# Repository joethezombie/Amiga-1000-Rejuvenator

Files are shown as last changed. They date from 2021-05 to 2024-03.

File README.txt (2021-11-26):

Amiga 1000 Rejuvenator Re-creation Project
-------------------------------------------------------------------------------------------

Any projects, additions, alterations, derivatives, or improvements based on this
Amiga-1000-Rejuvenator project must be openly shared, including software or PLD coding.
Additionally, on top of the LICENSE specified, the amigalove.com logo and Greg Tibbs name
must always be present in digital releases, and prominently printed on physical
productions.

And with that out of the way...

Thanks to the extreme graciousness of Eric Hill (intric8 at amigalove.com), I had on loan
a Rejuvenator board for the Amiga 1000.  Originally created by Greg Tibbs, this Amiga 1000
hardware upgrade provides up to 2MB Chip Memory, an onboard ROM based kickstart, and an
A2000 style video slot.  Installation requires replacing the A1000's daughterboard with
the Rejuvenator.

This project aims to re-create the original Rejuvenator, and eventually improve on the
design.

Schematics and board artwork are complete, and have been fabricated and tested.  Several
design errors on the original Rejuvenator which required bodge wires and trace cuts to
rectify have been identified and eliminated in the new design.

Again, thanks to the unrelenting determination of Eric over at amigalove.com,
arrangements were made to send the board overseas to Matthias Heinrichs of A1K.org who
successfully solved the last piece of the puzzle and has provided the PLD code.
 
 It has been an abosulute pleasure working with these Amiga community staples!
 
 So what now?  The project will continue with the goal of improving on the original
 design.  Currently, work is being done to provide compatibility with Agnus 8375
 varieties (-10, -11, -16, -17) and replace the DRAM with more available surface mount
 options.

--joethezombie

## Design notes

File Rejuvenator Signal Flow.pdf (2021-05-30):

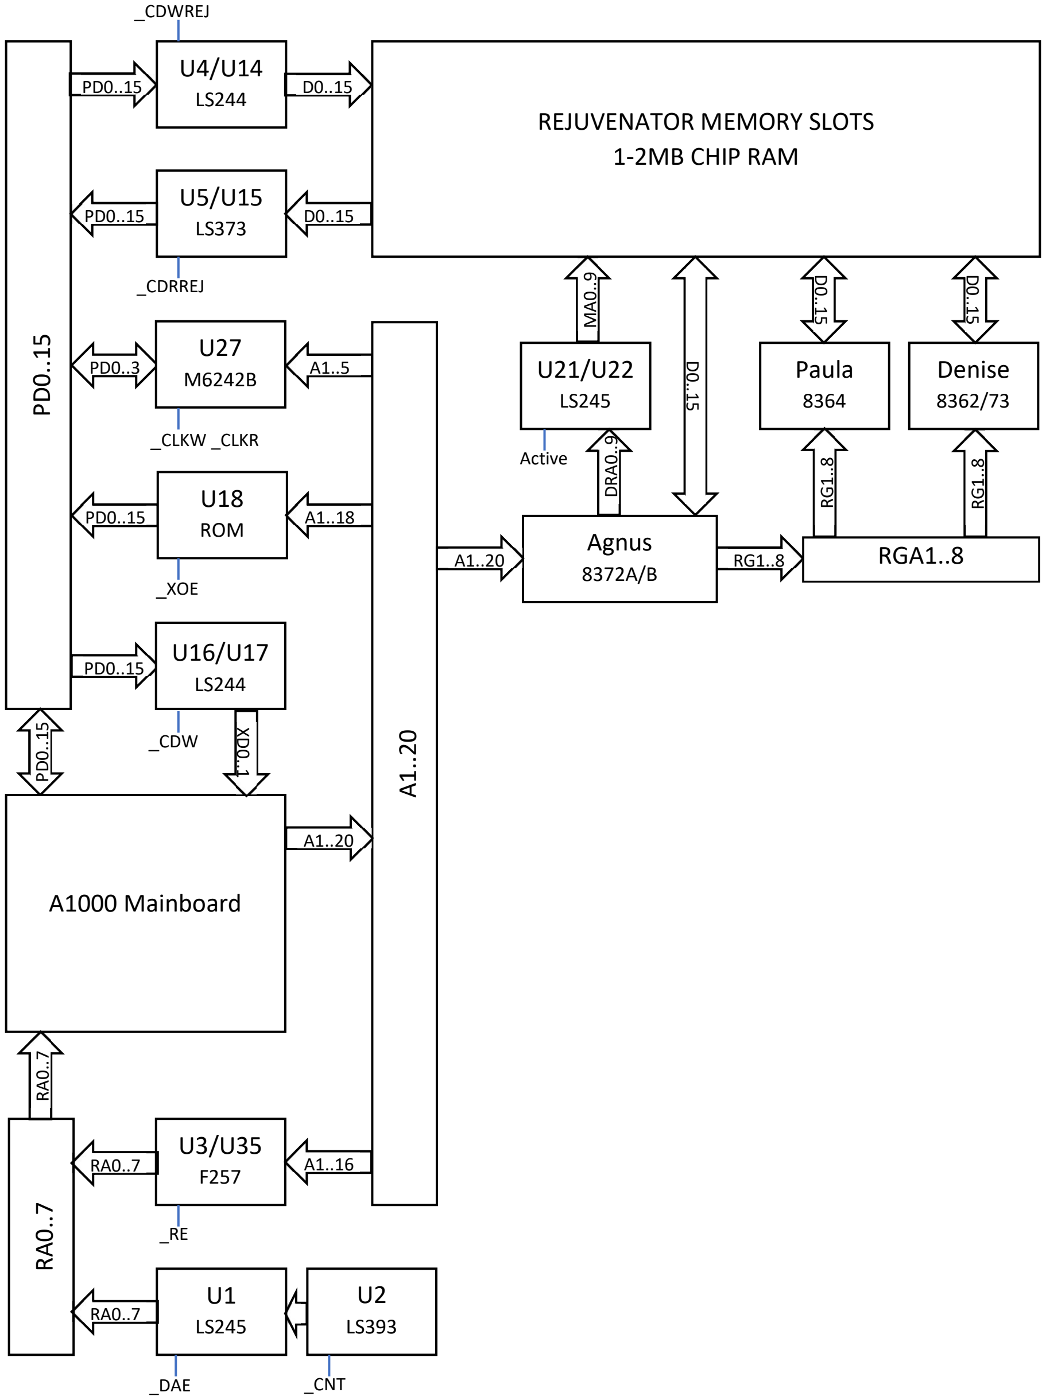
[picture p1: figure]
_CDWREJ; _CDRREJ; Denise; U18 ROM; U16/U17 LS244 PD⁰..15; A1000 Mainboard; _RE RA⁰..7; _DAE; _CNT; REJUVENATOR MEMORY SLOTS 1-2MB CHIP RAM; Paula 8364; Agnus; _XOE; _CLKW _CLKR; _CDW; Active

8372A/B A1..20 | RGA1..8 RG¹..8 | RG¹..8 D0..15 | D0..15 D0..15 DRA⁰..9 MA⁰..9 XD0..1 RA⁰..7

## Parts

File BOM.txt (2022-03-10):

Amiga 1000 Rejuvenator BOM (not yet complete)
----------------------------------------
BOM does not include the Amiga custom chips, ROM, memory, or realtime clock.
BOM values always supersede schematic placeholders

Qty.1  Molex 22-14-2024 CONN RCPT    2POS  X1
Qty.1  Molex 22-14-2044 CONN RCPT    4POS  X14
Qty.1  Molex 22-14-2064 CONN RCPT    6POS  X15
Qty.4  Molex 22-14-2084 CONN RCPT    8POS  U40, U41
Qty.8  Molex 22-14-2104 CONN RCPT   10POS  U36, U37, U38, U39
Qty.1  PLCC CONN SOCKET             84POS  U19 (Agnus)
Qty.2  CONN IC DIP SOCKET   15.24mm 48POS  U20, U25 (Paula, Denise)
Qty.1  CONN IC DIP SOCKET   15.24mm 40POS  U18 (ROM)
Qty.10 CONN IC DIP SOCKET    7.62mm 20POS  U28, U29 (PAL16L8) U6-U16 (RAM Sockets)
Qty.1  CONN IC DIP SOCKET    7.62mm 18POS  U27 (realtime clock)
Qty.2  CONN IC DIP SOCKET    7.62mm 24POS  U30, U31 (PAL20L8)
Qty.6  CONN HEADER VERT MACH 2.54mm 24POS  Circular Machined pin header, 16mm overall length preferred (To mainboard sockets)
Qty.2  47uF  16V Radial Capacitor          C23, C32
Qty.1  220uF 16V Radial Capacitor          C20
Qty.1  22uF  16V Radial Capacitor          C37
Qty.1  20pF  16V CER CAP Radial            C21
Qty.1  ~22pF Trimmer Capacitor             C24 (Fine tune for RTC.  Value should envelope 22pF)
Qty.33 .1uF  16V CER CAP Radial            C30, Decoupling Capacitors
Qty.2  RES ARRAY 8 RES   33 OHM 16DIP      U23, U24
Qty.1  RES ARRAY 9 RES 3.3k OHM 10SIP      RP5
Qty.4  RES ARRAY 9 RES 2.2k OHM 10SIP      RP1, RP2, RP3, RP4
Qty.2  DIODE GEN PURP 100V 200MA DO35      CR1, CR2
Qty.2  SN74AHCT245N                        U26, U34
Qty.3  SN74ALS245AN                        U1, U21, U22
Qty.4  SN74ALS244CN                        U4, U14, U16, U17
Qty.1  SN74LS393N                          U2
Qty.2  SN74ALS373N                         U5, U15
Qty.2  MC74F257AN                          U3, U35
Qty.1  SN74AHCT74N                         U32
Qty.1  T74LS04B1                           U33

Circular Machined pin header WARNING
---------------------------------------------------------------------------------------------------------------------------
Circular Machine pin headers in extended length might be difficult to find.  You can use additional 48-pin sockets to build
the height up on the mainboard before equiping the rejuvenator if necessary. (Thanks to Mattsoft for this observation)

If you use shorter pin headers without extending the socksets, the board will sit very low and will block the power LED
connector.  You should also be mindful of possible shorting on the bottom of the Rejuvenator through hole components against
the CIA and ROM chips on the Amiga 1000 motherboard.  An isolation shim might be a good idea if you opt to sit low.

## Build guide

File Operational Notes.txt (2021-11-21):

Very preliminary... much to do here, stay tuned.

Mainboard:

CAS Header (U5M on mainboard):
    Rejuvenator holds _RGAE and _DAE high, and disconnects _ARW _ROME _PALOPE.
     _ARW leads to pin 16 of original Agnus socket, that pin is unused in Rejuv.
     _ROME connected to Rejuve via EN header, pin 13, then back up CAS header pin 7 where it is unconnected.
     _PALOPE is connected only to expansion port.  Exact function is unknown, perhaps never used.
             No equation present in DPALCAS (pin is nc). Not present in A2000.

EN Header (U5L on mainboard):
     Rejuvenator disconnects _DBR _DAE _RGAE _RE
     _DBR leads to pin 15 of original Agnus socket, that pin is unused in Rejuvenator.
     _DAE and _RGAE held high through mainboard connection to CAS header (see above)
     _RE still connected to Rejvenator via CAS header, pin 8.

  Because _RGAE is held high, LS244 U4J pins 1 and 19 are high.  Disables the Y outputs, leaving output pins in Z state.
  (Disables A1-8 Address lines from hitting the RGA bus)

  Because _DAE is held high, F374 U2H pin 1 is high.  Disables the OE, leaving the output pins in Z state.
  (Disables DRA lines from original Agnus from hitting the RA bus)

Clip Leads to Rejuvenator:
    RMBCLKS clip lead - Reset MainBoard CLocKs - Holds the mainboard clocks in reset using R8/C32 delay timer.  Allows
                        time for the Rejuvenator to initialize before the mainboard becomes active.
    28MHz - Gathers 28MHz from the mainboard.
    12V - 12V from the mainboard, for recharging the clock battery.

  Memory Config Jumpers:
    When using the ROM option (JP100 open), you can configure the mainboard RAM using the J101 and J102:
       J101 J102
        ON   ON   -  C00000 512kb    autoconfig (slow-fast RAM)
        ON   OFF  -  C00000 1Meg     autoconfig (slow-fast RAM) (if you have 1Meg Mainboard Hack?)
        OFF  ON   -  700000 512kb/1M addmem required
        OFF  OFF  -  A80000 512Kb/1M addmem required
             
    When JP100 is closed, Rejuvenator will store 256K ROM file from disk into the front RAM expansion.
    The remaining 256K on the mainboard can be moved to A0000 or 70000 by changing J101 and J102.
       J101 J102
        X    X    -  F00000-FFFFFF WCS 256K/512K Addmem
        OFF  ON   -  700000-7FFFFF Addmem Required
        OFF  OFF  -  A8000-B7FFF   Addmem Required

  Signals:

    _ROM01 - generated on pin 12 of U29, SBGCAS
    If _ROM01 is low: Enable the ROM chips at motherboard positions U2N, U2P, U5N, U5P.
    (ROM01 is connected to Pin 22 (OE) of all 4 ROM positions on the mainboard.

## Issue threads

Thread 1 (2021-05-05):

Verify signal names, states (input, output, or bidirectional), and polarity (active low).

joethezombie, 2021-05-05:
Currently, most of the signals are not directional.  The signal names are also not standardized to Amiga schematics.  Finally, need to identify which signals are active low.

joethezombie, 2021-05-13:
Signal names for the [PAL diagrams](https://github.com/joethezombie/Amiga-1000-Rejuvenator/blob/master/PLD/PAL%20Best%20Guess%20Effort.pdf) have been updated, including active low identification.  Next up will be the schematics.

joethezombie, 2021-05-15:
Signal names on the board schematics and artwork have been mostly updated, including active low identification.  Directional or 3-state adjustments are still needed.

joethezombie, 2021-05-27:
Added signal direction for Agnus 8372B

joethezombie, 2021-05-30:
Signal direction mostly completed.  Schematics now pass ERC check error free!  Will continue to look at the remaining warnings.

graphiteavatar, 2021-05-30:
Very cool. Has there been any forward motion on the PAL chips.  I have some friends that may be able to extract the information, but is that already done and now it’s just deciding it?  I an going to  finish cleaning and testing mine and hopefully there is no damage to my pals.

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

joethezombie, 2021-05-30:
> Very cool. Has there been any forward motion on the PAL chips.

Slowly working forward on the PAL front.  I was unable to read them.  You can read of my strategy and efforts in the PLD folder.

The PALs are fuse-protected, and since they are early PALs and not GALs, they are not susceptible to the voltage manipulation bypass used on GALs.    Further, they use feedback, which forms a rudimentary memory system making analysis very difficult.  Finally, U30 and U31 are larger PALs (20L8) so current tools developed mainly for 16L8 are not easily adapted to the increased number of inputs/outputs.

But I remain hopeful.  Intric8 from amigalove.com (the owner of the board) is working with a1k.org, a much more capable team with a impressive history of reverse engineering, who are very familiar with the native signaling.  Perhaps they will have much better luck on that front.

In the meantime, I am continuing my efforts.  I've recently completed a memory/function map which details whats happening on the board, and what chip enables are toggled depending on memory addresses.  Using that, I hope to create  baseline  logic to at least get the board to boot.  From there we can add memory mapping and expansion port compatibility.

But I'm very interested.  If you and your friends are able to read yours, that would be insanely awesome.  It's the last piece of the puzzle!

graphiteavatar, 2021-08-29:
Hello. Is there a schematic or can you point out the clip lead layout. The rejuvinator mother board was damaged and i can see the reclk silkscreen but can’t se which of the other two is what.  Thanks.

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

joethezombie, 2021-08-31:
The full schematics and board artwork are available in the [KiCAD](https://github.com/joethezombie/Amiga-1000-Rejuvenator/tree/master/KiCAD/Amiga-Rejuvenator) folder.  Use KiCAD to view it.  To directly answer your question, there are 3 clip leads that lead to the Amiga 1000.  RMBCLKS is near the Kickstart selection jumper.  28MHZ is above the battery close to R1.  And +12V is between C29 and the battery.  Consult the [Rejuvenator Manual](http://amiga.resource.cx/manual/Rejuvenator.pdf) for exact placement of the clips on the A1000 mainboard.
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

graphiteavatar, 2021-08-31:
Thanks. I used that pic and soldered them back on. I am thinking the battery damage is too extensive and I am going to have to replace the pc board.  My machine won’t boot.

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

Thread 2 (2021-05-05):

BOM missing

joethezombie, 2021-05-05:
Upload BOM listings.

joethezombie, 2021-05-06:
Partial BOM uploaded.  Stay tuned...

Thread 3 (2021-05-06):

Update board silkscreen with proper capacitor and resistor values

joethezombie, 2021-05-06:
Current silkscreen was best-guess effort.  Proper values were gleaned of intric8's actual Rejuvenator board.  Need to update the artwork with the proper values.

joethezombie, 2021-05-15:
Artwork has been updated to actual build values.

Closed 2021-05-15.

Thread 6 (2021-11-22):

Replace 28MHz clip-lead with PLL

nonarkitten, 2021-11-22:
Clip leads are notoriously risky.

A 4046 could be used to regenerate the 28MHz clock from a 7 or 14MHz source. There seem to be a few options for the clock source, CDAC is probably the best one from Denise. A simple RC with a pF varicap ought to allow for tuning of the clock if there's a problematic phase shift, but I doubt it's needed.

joethezombie, 2022-03-10:
Sorry for the late reply... I wasn't getting notifications of opened issues.

Thanks for this.  I'll look into it for the improved version of the board.

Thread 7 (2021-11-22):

No 12V should be needed for RTC

nonarkitten, 2021-11-22:
Clip leads are dangerous.

I'm assuming the 12V was used for the RTC because 5V wasn't always 5V and would have made the battery more difficult to charge. Or because Commodore being cheap, didn't want a Lithium rechargeable cell and opted for Nickel Cadmium time-bombs.

It would be a big improvement to simply use 5V and a lithium rechargeable coin cell battery as-per the datasheet. These are much more common nowadays and removes the need to pull 12V from anywhere as well as the potentially explosive NiCd.

ogg1e, 2022-01-02:
Was this not updated to support coin cell batteries? Is it attempting to charge them if you install one?

joethezombie, 2022-03-10:
Sorry for the late reply... I wasn't getting notifications of opened issues.

I agree completely with your observations.  This first iteration was meant to exactly copy the original design before any upgrades were made.  A new board is in design that will improve the RTC circuit, including battery type.  Alternative Agnus support will also be included, as well as more available surface mount RAM options.  We just wanted to make sure everything worked as expected before any changes.

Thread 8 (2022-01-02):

bom and schematic don't match

ogg1e, 2022-01-02:
BOM has 47uF for C32, schematic says 22uf.

BOM also doesn't state what caps are polarity and which aren't. Schematic states they all have polarity, but is that true?

joethezombie, 2022-03-10:
Sorry for the late reply... I wasn't getting notifications of opened issues.
The BOM always supersedes schematic placeholders.
As far as capacitor polarity, all electrolytic capacitors on the board are polarized.  Ceramic decoupling capacitors are not.

ogg1e, 2022-05-21:
Sorry, but I mean the schematic file in kicad, not the silkscreen.
The board I have shows R1 = 33 ohm on the silkscreen, but when you open up the sch in kicad, it's 47 ohm.

R1 is not listed in the BOM at all. What do I use for R1 in this situation?

Acill, 2022-05-21:
I have a 33 in mine.

On Sat, May 21, 2022 at 12:42 PM Gary Ogden ***@***.***>
wrote:

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

joethezombie, 2022-05-27:
R1 is interesting because the original bare Rejuvenator board is marked 33Ω.  But original populated boards have been found with 33Ω, 47Ω, or 68Ω resistors.  Consensus was it probably doesn't matter much.  It's there to protect Agnus from the flying lead connection, which isn't optimal.  Work is being done on the next revision of the board to eliminate the flying leads.

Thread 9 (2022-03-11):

Holes for Battery to small

olDirdey, 2022-03-11:
To small hole diameter at the batterie footprint. You can´t install a batterie without altering the legs.

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

joethezombie, 2022-03-11:
Thank you for reporting the issue.  The holes were made the same diameter as the original Rejuvenator, and a test fit with a battery I had on hand did fit.  Most likely new production batteries are not identical to ones from back in the day.  In any event, I will increase the diameter size to accommodate.

Also, please note the recent (yesterday) additions for the capacitors in the RTC circuit now located in the BOM.  The schematic values were placeholders.  The correct values for C21 and C30 have now been added, as well as a reference for the trimmer capacitor C24.

olDirdey, 2022-03-12:
Thank you joe for your reply. That´s true, most of the old style batteries have narrower legs. I measured 5 batteries from 2 different brands that I have laying around. They are between 0.98mm up to 1.04mm.

Good hint pointing out the parts for the RTC. I used parts that are common on memory expansions (22pf near clock and 100uf near batterie) but I will change the bigger 100uf near batterie to 0.1uf.

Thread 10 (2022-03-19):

PCB bit to wide in PSU direction

olDirdey, 2022-03-19:
Build and installed a few Rejuventors. All have in common that the space between PCB and PSU is not enaugh. Had to remove at least one PSU Screw to get the Rejuvenator fitted.

1) Yellow rectangle; Make PCB a bit smaller (1-1.5mm) to get more space between PSU and Rejuvenator Board.
2) Red rectangle; Add a notch to the pcb to get room for the grommet that holds the cable from psu to the mainboard.

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

Acill, 2022-03-19:
While true if you install it while the mainboard  is in the case like I
believe you have been, the manual for the original boards states to remove
the mainboard for the installation. I have found all the ones I do with it
out of the case work great and will go back in all together much easier.

-Paul R.
Acill

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

olDirdey, 2022-03-19:
The manual states it for easier installation. But the position is every time the same, you can´t move the rejuvenator if it´s installed.
So no difference if I install it inside the case or outside the case, the Space between PSU and Rejuvenator is to small. If the Rejuvenator is installed on the board the mounting holes for the psu did not align anymore.

Acill, 2022-03-26:
I  wonder if something changed in the board size from the original release
files to the current? I didnt have any problems with mine. I guess I need
to build another one from the current downloaded repository and see.

-Paul R.

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

olDirdey, 2022-03-26:
Must have to do with the Case, the PSU or somehting like that. Didn´t figured it out yet. I build few Rejuvenators. Some people have no problem with missing space, other as I do, have.

joethezombie, 2022-05-27:
Interesting enough, the reproduction board is actually narrower than the original for just this reason.  The angle You are the only one I know of with this issue.  The angle at the top left of the board was also made deeper to allow better clearance for the peg that fits there, as well as the hole in the middle of the board being larger.

I think we can shave a couple more mm off the edge of the board where the power supply sits without issue.  About how much more room are you needing?

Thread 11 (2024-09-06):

Video Slot

reinauer, 2024-09-06:
The original Rejuvenator had an A2000 video slot on a small riser board. Does this riser exist as a reproduction?

joethezombie, 2024-09-06:
Nearly... I created the schematics and board files.  I hope to test functionality this fall, as real life calms a bit.  Here's the teaser:
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

reinauer, 2024-09-07:
Wow very cool!

neurohide, 2025-03-15:
Wow, I would like to test it with the rgb2hdmi project, the cpld version for amiga 2000, do you think it is possible?

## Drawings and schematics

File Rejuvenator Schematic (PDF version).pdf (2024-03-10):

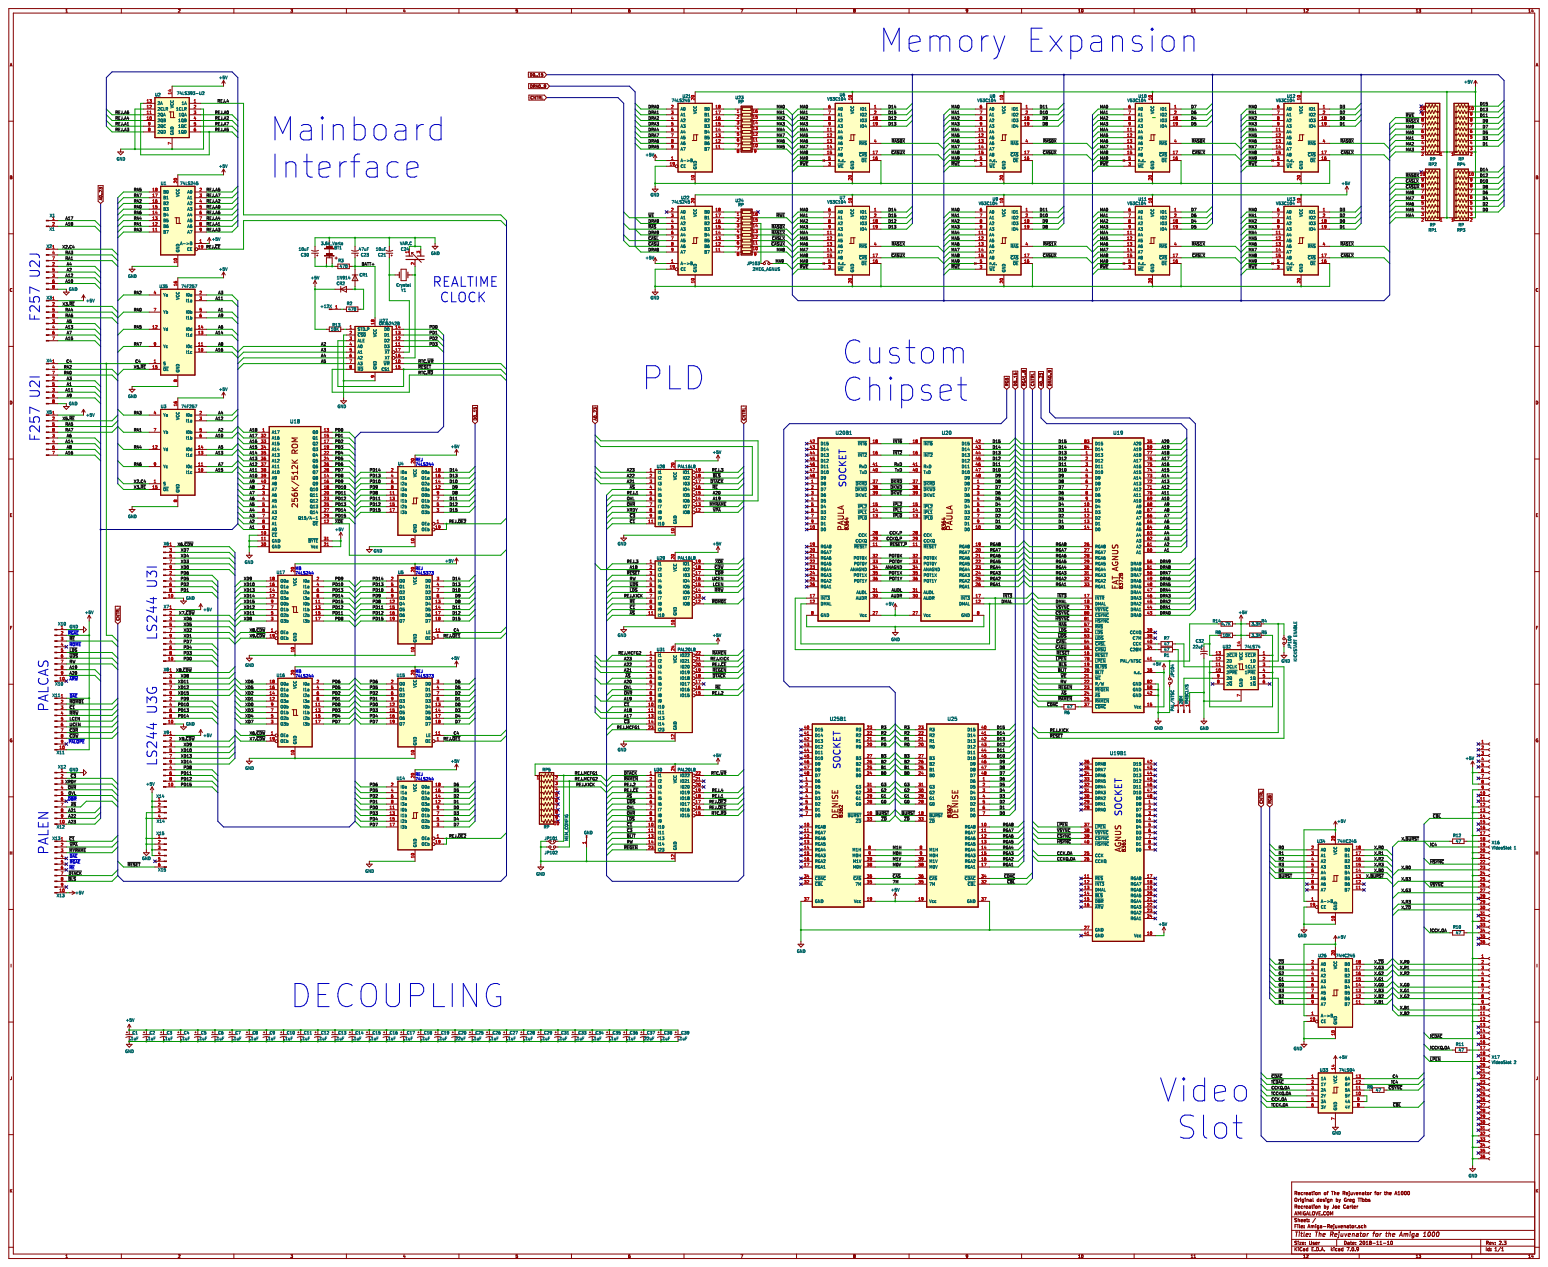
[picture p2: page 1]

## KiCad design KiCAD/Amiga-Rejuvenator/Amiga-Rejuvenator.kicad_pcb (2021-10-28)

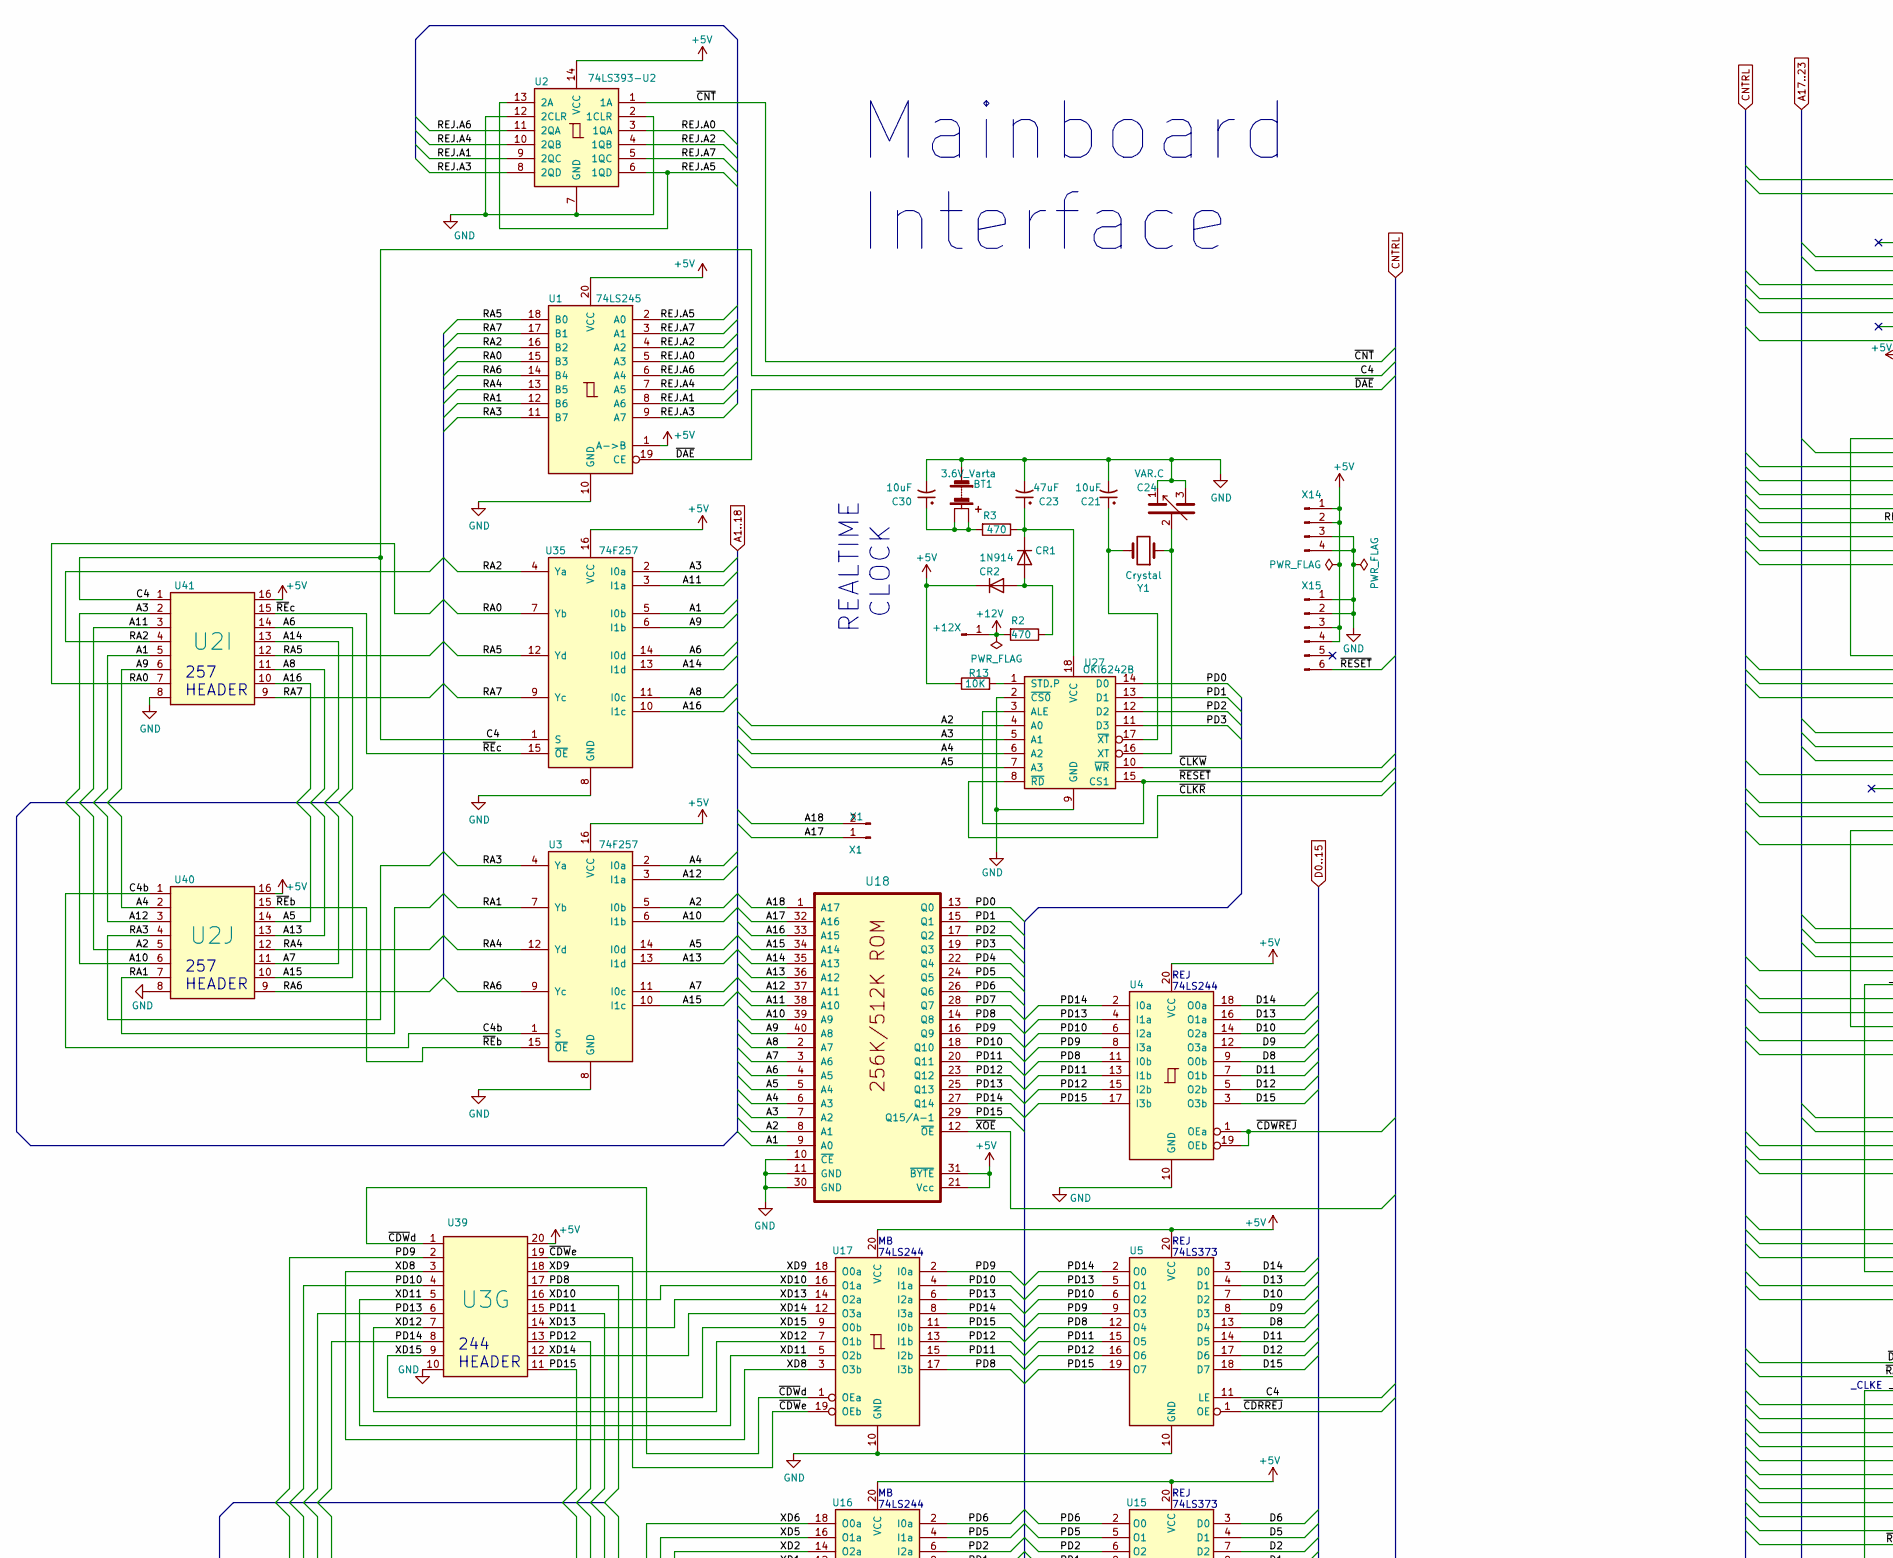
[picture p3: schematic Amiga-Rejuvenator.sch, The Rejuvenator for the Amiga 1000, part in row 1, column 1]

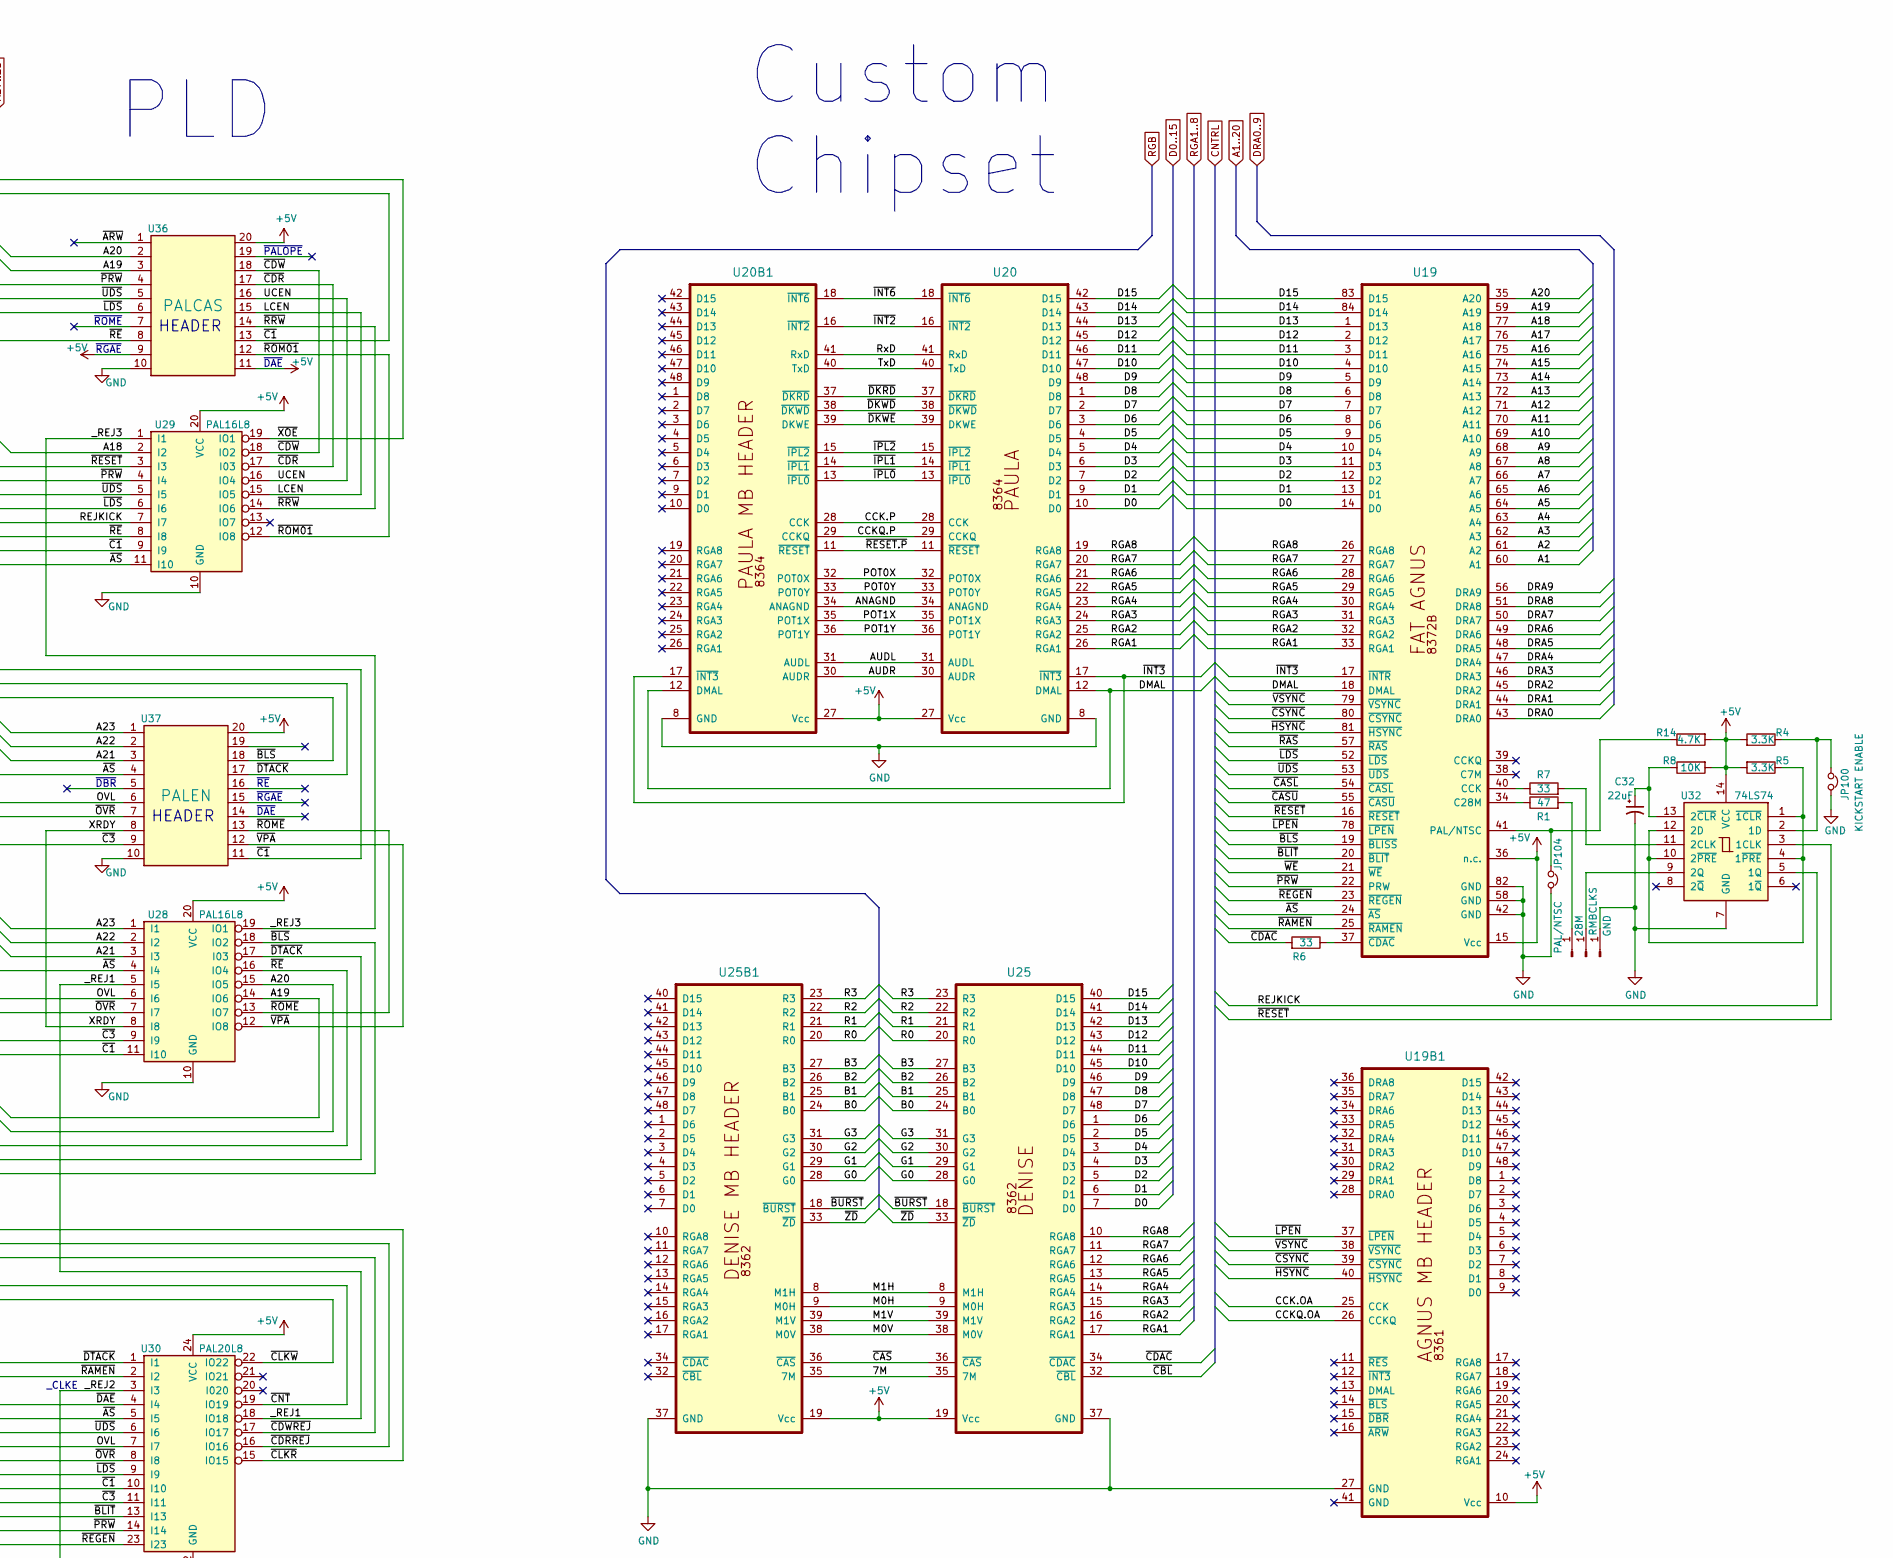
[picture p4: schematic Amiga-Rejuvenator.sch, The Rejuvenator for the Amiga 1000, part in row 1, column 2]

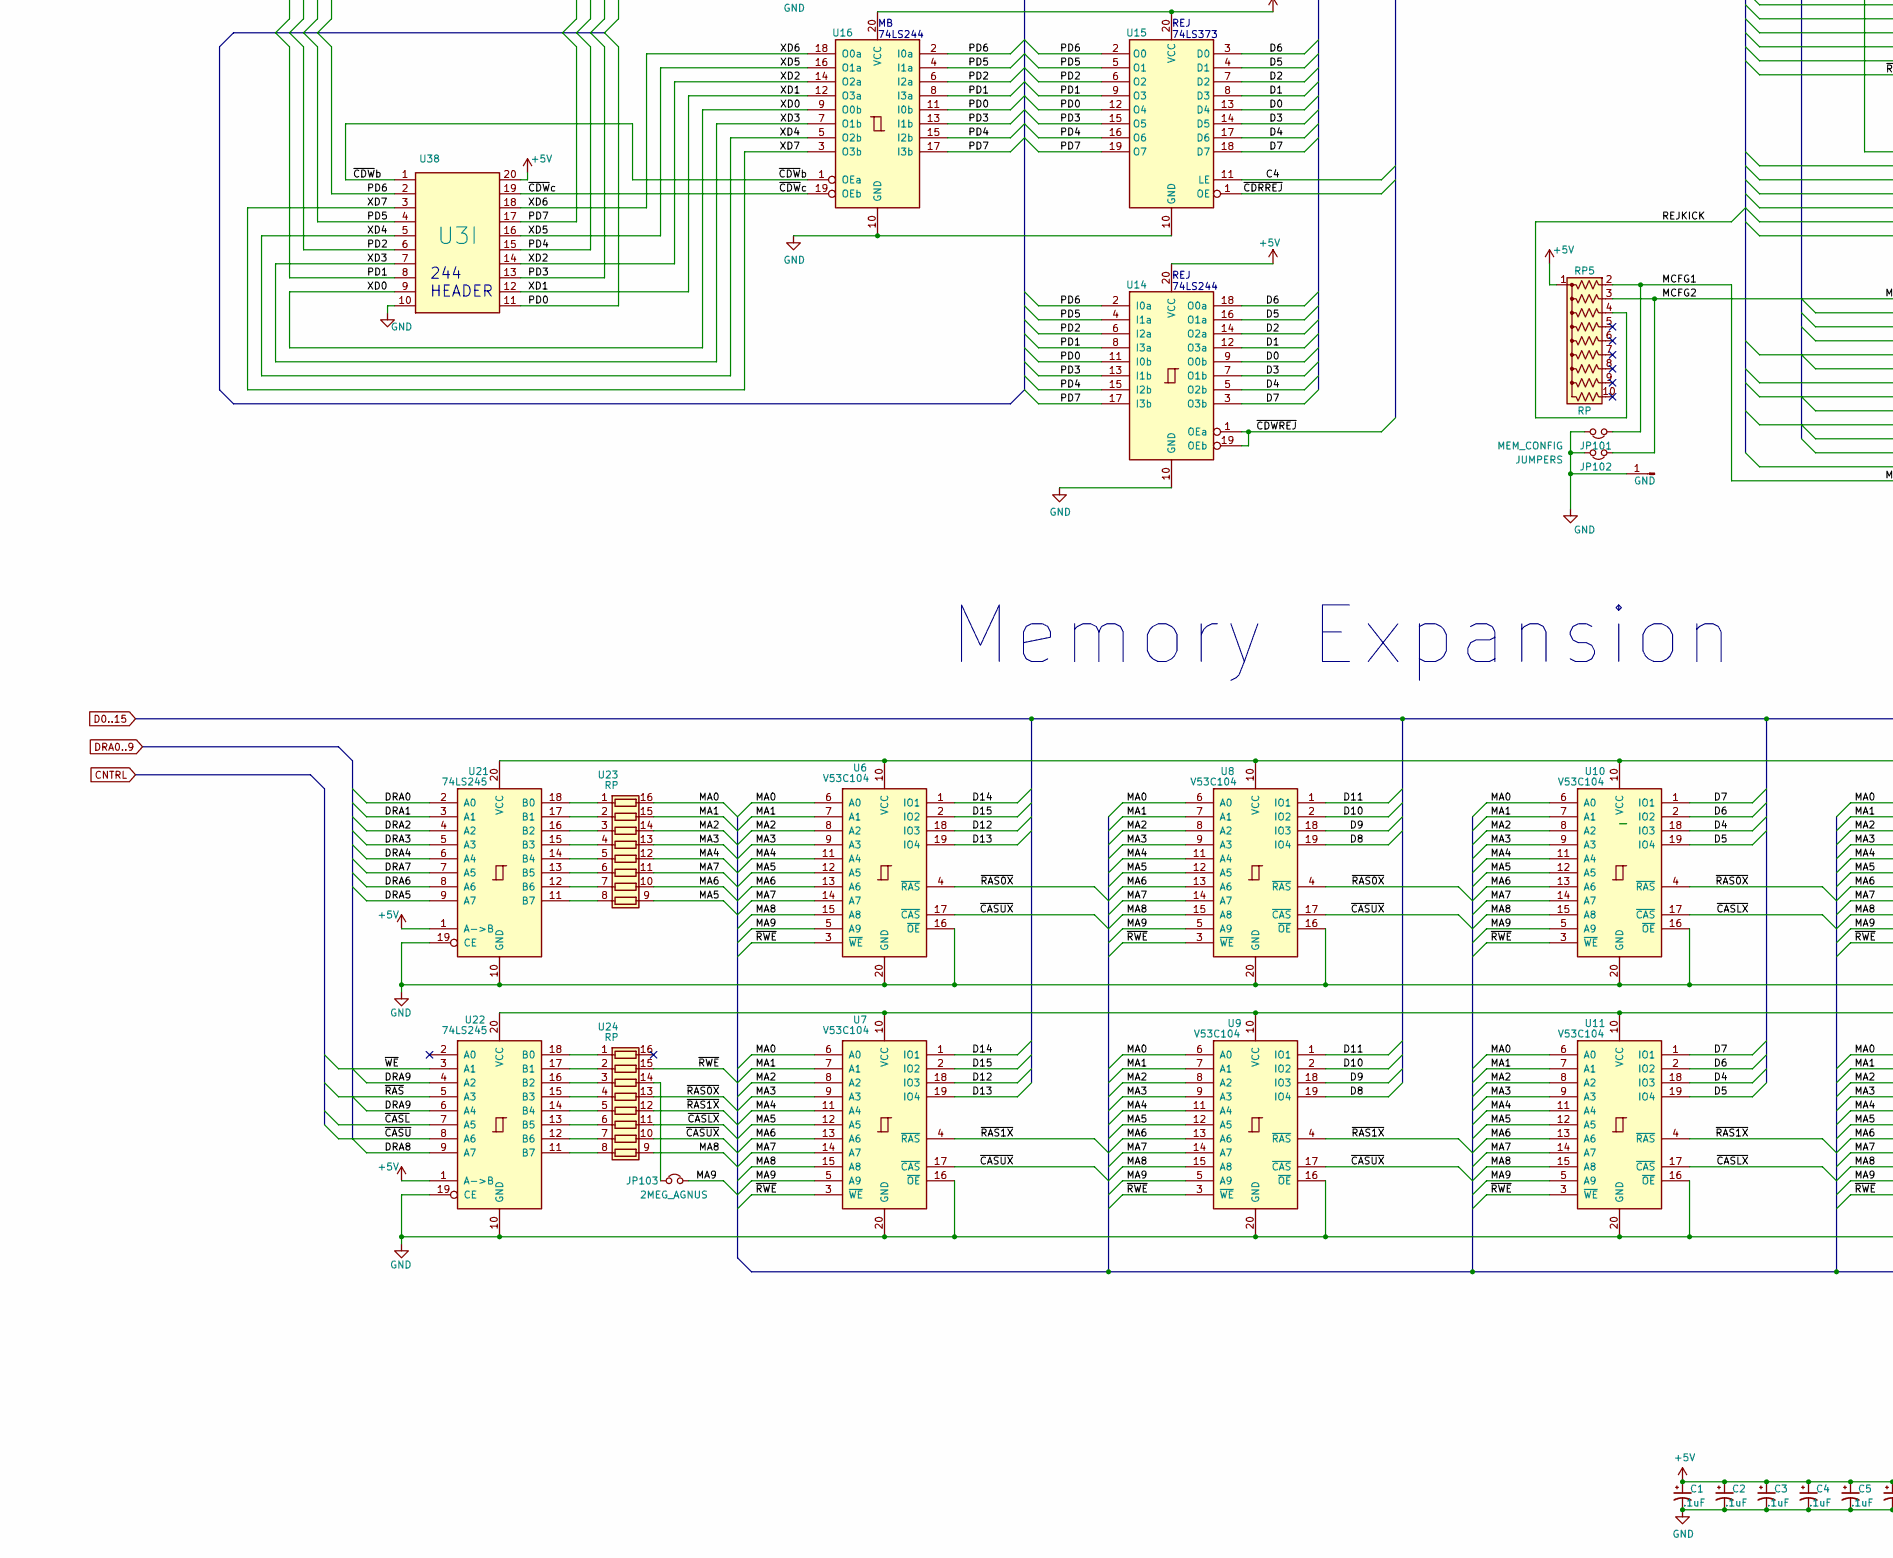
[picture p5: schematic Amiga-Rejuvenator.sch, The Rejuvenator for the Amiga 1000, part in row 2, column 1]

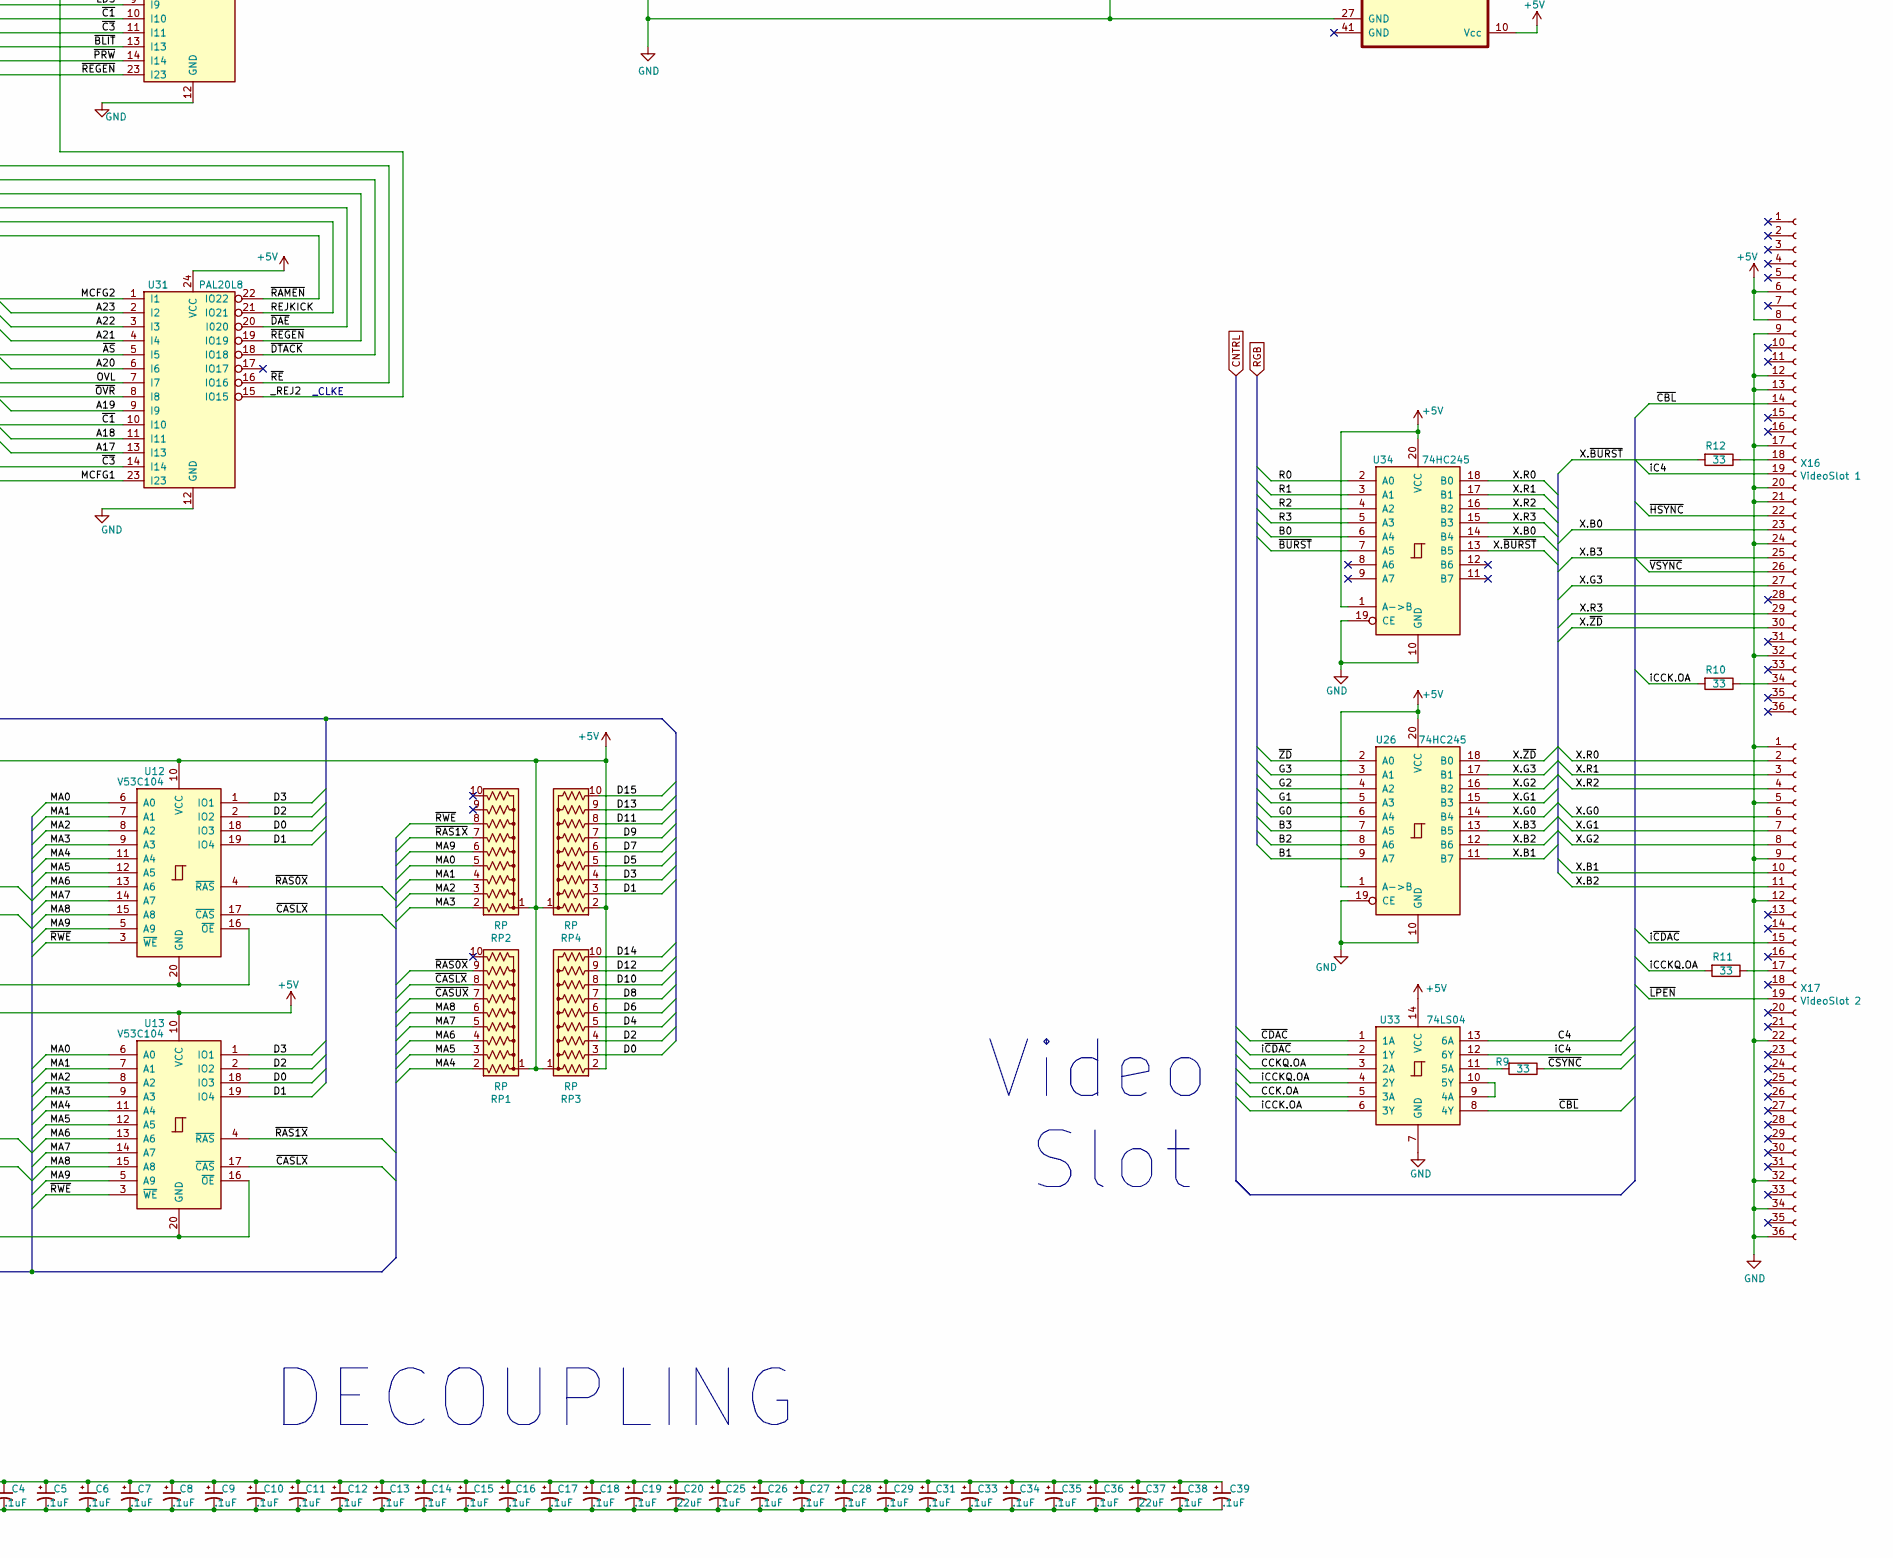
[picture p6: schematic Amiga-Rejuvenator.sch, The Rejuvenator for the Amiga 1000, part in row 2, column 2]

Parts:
BT1: 3.6V_Varta; 3.6V Varta
C1, C2, C3, C4, C5, C6, C7, C8, C9, C10, C11, C12, C13, C14, C15, C16, C17, C18, C19, C25, C26, C27, C28, C29, C31, C33, C34, C35, C36, C38, C39: .1uF; C_Rect_L7.0mm_W2.0mm_P5.00mm
C20, C32, C37: 22uF; C_Rect_L7.0mm_W2.0mm_P5.00mm
C21, C30: 10uF; C_Rect_L7.0mm_W2.0mm_P5.00mm
C23: 47uF; C_Rect_L7.0mm_W2.0mm_P5.00mm
C24: VAR.C; variable_capacitor
CR1, CR2: 1N914; D_DO-35_SOD27_P12.70mm_Horizontal
J1, J18: GND; PinHeader_1x01_P2.54mm_Vertical
J15: 28M; PinHeader_1x01_P2.54mm_Vertical
J17: RMBCLKS; PinHeader_1x01_P2.54mm_Vertical
J19: +12X; PinHeader_1x01_P2.54mm_Vertical
JP100: KICKSTART ENABLE; PinHeader_1x02_P2.54mm_Horizontal
JP101: MEM_CONFIG; PinHeader_1x02_P2.54mm_Vertical
JP102: JUMPERS; PinHeader_1x02_P2.54mm_Vertical
JP103: 2MEG_AGNUS; PinHeader_1x02_P2.54mm_Vertical
JP104: PAL/NTSC; PinHeader_1x02_P2.54mm_Vertical
R1: 47; R_Axial_DIN0207_L6.3mm_D2.5mm_P15.24mm_Horizontal
R2, R3: 470; R_Axial_DIN0207_L6.3mm_D2.5mm_P15.24mm_Horizontal
R4, R5: 3.3K; R_Axial_DIN0207_L6.3mm_D2.5mm_P15.24mm_Horizontal
R6, R7: 33; R_Axial_DIN0309_L9.0mm_D3.2mm_P12.70mm_Horizontal
R8, R13: 10K; R_Axial_DIN0207_L6.3mm_D2.5mm_P15.24mm_Horizontal
R9, R10, R11, R12: 33; R_Axial_DIN0207_L6.3mm_D2.5mm_P15.24mm_Horizontal
R14: 4.7K; R_Axial_DIN0309_L9.0mm_D3.2mm_P12.70mm_Horizontal
RP1, RP2, RP3, RP4, RP5: RP; R_Array_SIP10
U1, U21, U22: 74LS245; DIP-20_W7.62mm
U2: 74LS393-U2; DIP-14_W7.62mm
U3, U35: 74F257; DIP-16_W7.62mm
U4, U14, U16, U17: 74LS244-U16,U17; DIP-20_W7.62mm
U5, U15: 74LS373; DIP-20_W7.62mm
U6, U7, U8, U9, U10, U11, U12, U13: V53C104; DIP-20_W7.62mm
U18: 512K-ROM; DIP-40_W15.24mm
U19: 8372-FatAgnus; PLCC-84_THT-Socket
U19B1: 8361-Agnus-Socket; DIP-48_W15.24mm_Socket
U20: 8364-Paula; DIP-48_W15.24mm_Socket
U20B1: 8364-Paula-Socket; 48pin_blank_socket
U23, U24: RP; DIP-16_W7.62mm
U25: 8362-Denise; DIP-48_W15.24mm_Socket
U25B1: 8362-Denise-Socket; 48pin_blank_socket
U26, U34: 74HC245; DIP-20_W7.62mm
U27: OKI6242B; DIP-18_W7.62mm
U28, U29: PAL16L8; DIP-20_W7.62mm
U30, U31: PAL20L8; DIP-24_W7.62mm
U32: 74LS74; DIP-14_W7.62mm
U33: 74LS04; DIP-14_W7.62mm
U36: PALCAS; MOLEX_4455-10_W7.62mm[x2-R]
U37: PALEN; MOLEX_4455-10_W7.62mm[x2-R]
U38: U3I; MOLEX_4455-10_W7.62mm[x2]
U39: U3G; MOLEX_4455-10_W7.62mm[x2]
U40: U2J; MOLEX_4455-8_W7.62mm[x2]
U41: U2I; MOLEX_4455-8_W7.62mm[x2]
X1: X1; MOLEX_4455-2_W7.62mm
X14: X14; MOLEX_4455-4_W7.62mm
X15: X15; MOLEX_4455-6_W7.62mm
X16: VideoSlot 1; PinHeader_2x18_P2.54mm_Vertical
X17: VideoSlot 2; PinHeader_2x18_P2.54mm_Vertical
Y1: Crystal; Crystal_AT310_D3.0mm_L10.0mm_Vertical

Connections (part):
+5V: C1.1, C2.1, C3.1, C4.1, C5.1, C6.1, C7.1, C8.1, C9.1, C10.1, C11.1, C12.1, C13.1, C14.1, C15.1, C16.1, C17.1, C18.1, C19.1, C20.1, C25.1, C26.1, C27.1, C28.1, C29.1, C31.1, C33.1, C34.1, C35.1, C36.1, C37.1, C38.1, C39.1, CR2.1 (K), R4.2, R5.2, R8.2, R13.1, R14.2, RP1.1 (common), RP2.1 (common), RP3.1 (common), RP3.2 (R1), RP4.1 (common), RP4.2 (R1), RP5.1 (common), U1.1 (A->B), U1.20 (VCC), U2.14 (VCC), U3.16 (VCC), U4.20 (VCC), U5.20 (VCC), U6.10 (VCC), U7.10 (VCC), U8.10 (VCC), U9.10 (VCC), U10.10 (VCC), U11.10 (VCC), U12.10 (VCC), U13.10 (VCC), U14.20 (VCC), U15.20 (VCC), U16.20 (VCC), U17.20 (VCC), U18.21 (Vcc), U18.31 (~BYTE), U19.15 (Vcc), U19.36 (n.c.), U19B1.10 (Vcc), U20.27 (Vcc), U20B1.27 (Vcc), U21.1 (A->B), U21.20 (VCC), U22.1 (A->B), U22.20 (VCC), U25.19 (Vcc), U25B1.19 (Vcc), U26.1 (A->B), U26.20 (VCC), U28.20 (VCC), U29.20 (VCC)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
+12V: J19.1, R2.2
/7M: U25.35 (7M), U25B1.35 (7M)
/A1: U18.9 (A0), U19.60 (A1), U35.5 (I0b), U41.5
/A2: U3.5 (I0b), U18.8 (A1), U19.61 (A2), U27.4 (A0), U40.5
/A3: U18.7 (A2), U19.62 (A3), U27.5 (A1), U35.2 (I0a), U41.2
/A4: U3.2 (I0a), U18.6 (A3), U19.63 (A4), U27.6 (A2), U40.2
/A5: U3.14 (I0d), U18.5 (A4), U19.64 (A5), U27.7 (A3), U40.14
/A6: U18.4 (A5), U19.65 (A6), U35.14 (I0d), U41.14
/A7: U3.11 (I0c), U18.3 (A6), U19.66 (A7), U40.11
/A8: U18.2 (A7), U19.67 (A8), U35.11 (I0c), U41.11
/A9: U18.40 (A8), U19.68 (A9), U35.6 (I1b), U41.6
/A10: U3.6 (I1b), U18.39 (A9), U19.69 (A10), U40.6
/A11: U18.38 (A10), U19.70 (A11), U35.3 (I1a), U41.3
/A12: U3.3 (I1a), U18.37 (A11), U19.71 (A12), U40.3
/A13: U3.13 (I1d), U18.36 (A12), U19.72 (A13), U40.13
/A14: U18.35 (A13), U19.73 (A14), U35.13 (I1d), U41.13
/A15: U3.10 (I1c), U18.34 (A14), U19.74 (A15), U40.10
/A16: U18.33 (A15), U19.75 (A16), U35.10 (I1c), U41.10
/A17: U18.32 (A16), U19.76 (A17), U31.13 (I13), X1.1
/A18: U18.1 (A17), U19.77 (A18), U29.2 (I2), U31.11 (I11), X1.2
/A19: U19.59 (A19), U28.14 (IO6), U31.9 (I9), U36.3
/A20: U19.35 (A20), U28.15 (IO5), U31.6 (I6), U36.2
/A21: U28.3 (I3), U31.4 (I4), U37.3
/A22: U28.2 (I2), U31.3 (I3), U37.2
/A23: U28.1 (I1), U31.2 (I2), U37.1
/ANAGND: U20.34 (ANAGND), U20B1.34 (ANAGND)
/AUDL: U20.31 (AUDL), U20B1.31 (AUDL)
/AUDR: U20.30 (AUDR), U20B1.30 (AUDR)
/B0: U25.24 (B0), U25B1.24 (B0), U34.6 (A4)
/B1: U25.25 (B1), U25B1.25 (B1), U26.9 (A7)
/B2: U25.26 (B2), U25B1.26 (B2), U26.8 (A6)
/B3: U25.27 (B3), U25B1.27 (B3), U26.7 (A5)
/C4: U5.11 (LE), U15.11 (LE), U33.13 (6A), U35.1 (S), U41.1
/C4b: U3.1 (S), U40.1
/CCK.OA: U19B1.25 (CCK), U33.5 (3A)
/CCK.P: U20.28 (CCK), U20B1.28 (CCK)
/CCKQ.OA: U19B1.26 (CCKQ), U33.3 (2A)
/CCKQ.P: U20.29 (CCKQ), U20B1.29 (CCKQ)
/D0: RP3.3 (R2), U12.18 (IO3), U13.18 (IO3), U14.9 (O0b), U15.13 (D4), U19.14 (D0), U20.10 (D0), U25.7 (D0)
/D1: RP4.3 (R2), U12.19 (IO4), U13.19 (IO4), U14.12 (O3a), U15.8 (D3), U19.13 (D1), U20.9 (D1), U25.6 (D1)
/D2: RP3.4 (R3), U12.2 (IO2), U13.2 (IO2), U14.14 (O2a), U15.7 (D2), U19.12 (D2), U20.7 (D2), U25.5 (D2)
/D3: RP4.4 (R3), U12.1 (IO1), U13.1 (IO1), U14.7 (O1b), U15.14 (D5), U19.11 (D3), U20.6 (D3), U25.4 (D3)
/D4: RP3.5 (R4), U10.18 (IO3), U11.18 (IO3), U14.5 (O2b), U15.17 (D6), U19.10 (D4), U20.5 (D4), U25.3 (D4)
/D5: RP4.5 (R4), U10.19 (IO4), U11.19 (IO4), U14.16 (O1a), U15.4 (D1), U19.9 (D5), U20.4 (D5), U25.2 (D5)
/D6: RP3.6 (R5), U10.2 (IO2), U11.2 (IO2), U14.18 (O0a), U15.3 (D0), U19.8 (D6), U20.3 (D6), U25.1 (D6)
/D7: RP4.6 (R5), U10.1 (IO1), U11.1 (IO1), U14.3 (O3b), U15.18 (D7), U19.7 (D7), U20.2 (D7), U25.48 (D7)
/D8: RP3.7 (R6), U4.9 (O0b), U5.13 (D4), U8.19 (IO4), U9.19 (IO4), U19.6 (D8), U20.1 (D8), U25.47 (D8)
/D9: RP4.7 (R6), U4.12 (O3a), U5.8 (D3), U8.18 (IO3), U9.18 (IO3), U19.5 (D9), U20.48 (D9), U25.46 (D9)
/D10: RP3.8 (R7), U4.14 (O2a), U5.7 (D2), U8.2 (IO2), U9.2 (IO2), U19.4 (D10), U20.47 (D10), U25.45 (D10)
/D11: RP4.8 (R7), U4.7 (O1b), U5.14 (D5), U8.1 (IO1), U9.1 (IO1), U19.3 (D11), U20.46 (D11), U25.44 (D11)
/D12: RP3.9 (R8), U4.5 (O2b), U5.17 (D6), U6.18 (IO3), U7.18 (IO3), U19.2 (D12), U20.45 (D12), U25.43 (D12)
/D13: RP4.9 (R8), U4.16 (O1a), U5.4 (D1), U6.19 (IO4), U7.19 (IO4), U19.1 (D13), U20.44 (D13), U25.42 (D13)
/D14: RP3.10 (R9), U4.18 (O0a), U5.3 (D0), U6.1 (IO1), U7.1 (IO1), U19.84 (D14), U20.43 (D14), U25.41 (D14)
/D15: RP4.10 (R9), U4.3 (O3b), U5.18 (D7), U6.2 (IO2), U7.2 (IO2), U19.83 (D15), U20.42 (D15), U25.40 (D15)
/DMAL: U19.18 (DMAL), U20.12 (DMAL), U20B1.12 (DMAL)
/DRA0: U19.43 (DRA0), U21.2 (A0)
/DRA1: U19.44 (DRA1), U21.3 (A1)
/DRA2: U19.45 (DRA2), U21.4 (A2)
/DRA3: U19.46 (DRA3), U21.5 (A3)
/DRA4: U19.47 (DRA4), U21.6 (A4)
/DRA5: U19.48 (DRA5), U21.9 (A7)
/DRA6: U19.49 (DRA6), U21.8 (A6)
/DRA7: U19.50 (DRA7), U21.7 (A5)
/DRA8: U19.51 (DRA8), U22.9 (A7)
/DRA9: U19.56 (DRA9), U22.4 (A2), U22.6 (A4)
/G0: U25.28 (G0), U25B1.28 (G0), U26.6 (A4)
/G1: U25.29 (G1), U25B1.29 (G1), U26.5 (A3)
/G2: U25.30 (G2), U25B1.30 (G2), U26.4 (A2)
/G3: U25.31 (G3), U25B1.31 (G3), U26.3 (A1)
/LCEN: U29.15 (IO5), U36.15
/M0H: U25.9 (M0H), U25B1.9 (M0H)
/M0V: U25.38 (M0V), U25B1.38 (M0V)
/M1H: U25.8 (M1H), U25B1.8 (M1H)
/M1V: U25.39 (M1V), U25B1.39 (M1V)
/MA0: RP2.5 (R4), U6.6 (A0), U7.6 (A0), U8.6 (A0), U9.6 (A0), U10.6 (A0), U11.6 (A0), U12.6 (A0), U13.6 (A0), U23.16 (R1.2)
/MA1: RP2.4 (R3), U6.7 (A1), U7.7 (A1), U8.7 (A1), U9.7 (A1), U10.7 (A1), U11.7 (A1), U12.7 (A1), U13.7 (A1), U23.15 (R2.2)
/MA2: RP2.3 (R2), U6.8 (A2), U7.8 (A2), U8.8 (A2), U9.8 (A2), U10.8 (A2), U11.8 (A2), U12.8 (A2), U13.8 (A2), U23.14 (R3.2)
/MA3: RP2.2 (R1), U6.9 (A3), U7.9 (A3), U8.9 (A3), U9.9 (A3), U10.9 (A3), U11.9 (A3), U12.9 (A3), U13.9 (A3), U23.13 (R4.2)
/MA4: RP1.2 (R1), U6.11 (A4), U7.11 (A4), U8.11 (A4), U9.11 (A4), U10.11 (A4), U11.11 (A4), U12.11 (A4), U13.11 (A4), U23.12 (R5.2)
/MA5: RP1.3 (R2), U6.12 (A5), U7.12 (A5), U8.12 (A5), U9.12 (A5), U10.12 (A5), U11.12 (A5), U12.12 (A5), U13.12 (A5), U23.9 (R8.2)
/MA6: RP1.4 (R3), U6.13 (A6), U7.13 (A6), U8.13 (A6), U9.13 (A6), U10.13 (A6), U11.13 (A6), U12.13 (A6), U13.13 (A6), U23.10 (R7.2)
/MA7: RP1.5 (R4), U6.14 (A7), U7.14 (A7), U8.14 (A7), U9.14 (A7), U10.14 (A7), U11.14 (A7), U12.14 (A7), U13.14 (A7), U23.11 (R6.2)
/MA8: RP1.6 (R5), U6.15 (A8), U7.15 (A8), U8.15 (A8), U9.15 (A8), U10.15 (A8), U11.15 (A8), U12.15 (A8), U13.15 (A8), U24.9 (R8.2)
/MA9: JP103.1, RP2.6 (R5), U6.5 (A9), U7.5 (A9), U8.5 (A9), U9.5 (A9), U10.5 (A9), U11.5 (A9), U12.5 (A9), U13.5 (A9)
/MCFG1: JP101.2, RP5.2 (R1), U31.23 (I23)
/MCFG2: JP102.2, RP5.3 (R2), U31.1 (I1)
/OVL: U28.6 (I6), U30.7 (I7), U31.7 (I7), U37.6
/PD0: U14.11 (I0b), U15.12 (O4), U16.11 (I0b), U18.13 (Q0), U27.14 (D0), U38.11
/PD1: U14.8 (I3a), U15.9 (O3), U16.8 (I3a), U18.15 (Q1), U27.13 (D1), U38.8
/PD2: U14.6 (I2a), U15.6 (O2), U16.6 (I2a), U18.17 (Q2), U27.12 (D2), U38.6
/PD3: U14.13 (I1b), U15.15 (O5), U16.13 (I1b), U18.19 (Q3), U27.11 (D3), U38.13
/PD4: U14.15 (I2b), U15.16 (O6), U16.15 (I2b), U18.22 (Q4), U38.15
/PD5: U14.4 (I1a), U15.5 (O1), U16.4 (I1a), U18.24 (Q5), U38.4
/PD6: U14.2 (I0a), U15.2 (O0), U16.2 (I0a), U18.26 (Q6), U38.2
/PD7: U14.17 (I3b), U15.19 (O7), U16.17 (I3b), U18.28 (Q7), U38.17
/PD8: U4.11 (I0b), U5.12 (O4), U17.17 (I3b), U18.14 (Q8), U39.17
/PD9: U4.8 (I3a), U5.9 (O3), U17.2 (I0a), U18.16 (Q9), U39.2
/PD10: U4.6 (I2a), U5.6 (O2), U17.4 (I1a), U18.18 (Q10), U39.4
/PD11: U4.13 (I1b), U5.15 (O5), U17.15 (I2b), U18.20 (Q11), U39.15
/PD12: U4.15 (I2b), U5.16 (O6), U17.13 (I1b), U18.23 (Q12), U39.13
/PD13: U4.4 (I1a), U5.5 (O1), U17.6 (I2a), U18.25 (Q13), U39.6
/PD14: U4.2 (I0a), U5.2 (O0), U17.8 (I3a), U18.27 (Q14), U39.8
/PD15: U4.17 (I3b), U5.19 (O7), U17.11 (I0b), U18.29 (Q15/A-1), U39.11
/POT0X: U20.32 (POT0X), U20B1.32 (POT0X)
/POT0Y: U20.33 (POT0Y), U20B1.33 (POT0Y)
/POT1X: U20.35 (POT1X), U20B1.35 (POT1X)
/POT1Y: U20.36 (POT1Y), U20B1.36 (POT1Y)
/R0: U25.20 (R0), U25B1.20 (R0), U34.2 (A0)
/R1: U25.21 (R1), U25B1.21 (R1), U34.3 (A1)
/R2: U25.22 (R2), U25B1.22 (R2), U34.4 (A2)
/R3: U25.23 (R3), U25B1.23 (R3), U34.5 (A3)
/RA0: U1.15 (B3), U35.7 (Yb), U41.7
/RA1: U1.12 (B6), U3.7 (Yb), U40.7
/RA2: U1.16 (B2), U35.4 (Ya), U41.4
/RA3: U1.11 (B7), U3.4 (Ya), U40.4
/RA4: U1.13 (B5), U3.12 (Yd), U40.12
/RA5: U1.18 (B0), U35.12 (Yd), U41.12
/RA6: U1.14 (B4), U3.9 (Yc), U40.9
/RA7: U1.17 (B1), U35.9 (Yc), U41.9
/REJ.A0: U1.5 (A3), U2.3 (1QA)
/REJ.A1: U1.8 (A6), U2.9 (2QC)
/REJ.A2: U1.4 (A2), U2.4 (1QB)
/REJ.A3: U1.9 (A7), U2.8 (2QD)
/REJ.A4: U1.7 (A5), U2.10 (2QB)
/REJ.A5: U1.2 (A0), U2.6 (1QD), U2.13 (2A)
/REJ.A6: U1.6 (A4), U2.11 (2QA)
/REJ.A7: U1.3 (A1), U2.5 (1QC)
/REJKICK: RP5.4 (R3), U29.7 (I7), U31.21 (IO21), U32.5 (1Q)
/RGA1: U19.33 (RGA1), U20.26 (RGA1), U25.17 (RGA1)
/RGA2: U19.32 (RGA2), U20.25 (RGA2), U25.16 (RGA2)
/RGA3: U19.31 (RGA3), U20.24 (RGA3), U25.15 (RGA3)
/RGA4: U19.30 (RGA4), U20.23 (RGA4), U25.14 (RGA4)
/RGA5: U19.29 (RGA5), U20.22 (RGA5), U25.13 (RGA5)
/RGA6: U19.28 (RGA6), U20.21 (RGA6), U25.12 (RGA6)
/RGA7: U19.27 (RGA7), U20.20 (RGA7), U25.11 (RGA7)
/RGA8: U19.26 (RGA8), U20.19 (RGA8), U25.10 (RGA8)
/RxD: U20.41 (RxD), U20B1.41 (RxD)
/TxD: U20.40 (TxD), U20B1.40 (TxD)
/UCEN: U29.16 (IO4), U36.16
/X.B0: U34.14 (B4), X16.23
/X.B1: U26.11 (B7), X17.10
/X.B2: U26.12 (B6), X17.11
/X.B3: U26.13 (B5), X16.25
/X.G0: U26.14 (B4), X17.6
/X.G1: U26.15 (B3), X17.7
/X.G2: U26.16 (B2), X17.8
/X.G3: U26.17 (B1), X16.27
/X.R0: U34.18 (B0), X17.2
/X.R1: U34.17 (B1), X17.3
/X.R2: U34.16 (B2), X17.4
/X.R3: U34.15 (B3), X16.29
/X.~BURST: R12.2, U34.13 (B5)
/X.~ZD: U26.18 (B0), X16.30
/XD0: U16.9 (O0b), U38.9
/XD1: U16.12 (O3a), U38.12
/XD2: U16.14 (O2a), U38.14
/XD3: U16.7 (O1b), U38.7
/XD4: U16.5 (O2b), U38.5
/XD5: U16.16 (O1a), U38.16
/XD6: U16.18 (O0a), U38.18
/XD7: U16.3 (O3b), U38.3
/XD8: U17.3 (O3b), U39.3
/XD9: U17.18 (O0a), U39.18
/XD10: U17.16 (O1a), U39.16
/XD11: U17.5 (O2b), U39.5
/XD12: U17.7 (O1b), U39.7
/XD13: U17.14 (O2a), U39.14
/XD14: U17.12 (O3a), U39.12
/XD15: U17.9 (O0b), U39.9
/XRDY: U28.8 (I8), U37.8
/_REJ1: U28.5 (I5), U30.18 (IO18)
/_REJ2: U30.3 (I3), U31.15 (IO15)
/_REJ3: U28.19 (IO1), U29.1 (I1)
/iC4: U33.12 (6Y), X16.19
/iCCK.OA: R10.2, U33.6 (3Y)
/iCCKQ.OA: R11.2, U33.4 (2Y)
/i~CDAC: U33.2 (1Y), X17.15
/~AS: U19.24 (~AS), U28.4 (I4), U29.11 (I10), U30.5 (I5), U31.5 (I5), U37.4
/~BLIT: U19.20 (~BLIT), U30.13 (I13)
/~BLS: U19.19 (~BLISS), U28.18 (IO2), U37.18
/~BURST: U25.18 (~BURST), U25B1.18 (~BURST), U34.7 (A5)
/~C1: U28.11 (I10), U29.9 (I9), U30.10 (I10), U31.10 (I10), U36.13, U37.11
/~C3: U28.9 (I9), U30.11 (I11), U31.14 (I14), U37.9
/~CAS: U25.36 (~CAS), U25B1.36 (~CAS)
/~CASL: U19.54 (~CASL), U22.7 (A5)
/~CASLX: RP1.8 (R7), U10.17 (~CAS), U11.17 (~CAS), U12.17 (~CAS), U13.17 (~CAS), U24.11 (R6.2)
/~CASU: U19.55 (~CASU), U22.8 (A6)
/~CASUX: RP1.7 (R6), U6.17 (~CAS), U7.17 (~CAS), U8.17 (~CAS), U9.17 (~CAS), U24.10 (R7.2)
/~CBL: U25.32 (~CBL), U33.8 (4Y), X16.14
/~CDAC: R6.2, U25.34 (~CDAC), U33.1 (1A)
/~CDR: U29.17 (I03), U36.17
/~CDRREJ: U5.1 (OE), U15.1 (OE), U30.16 (IO16)
/~CDW: U29.18 (IO2), U36.18
/~CDWREJ: U4.1 (OEa), U4.19 (OEb), U14.1 (OEa), U14.19 (OEb), U30.17 (IO17)
/~CDW~b: U16.1 (OEa), U38.1
/~CDW~c: U16.19 (OEb), U38.19
/~CDW~d: U17.1 (OEa), U39.1
/~CDW~e: U17.19 (OEb), U39.19
/~CLKR: U27.8 (~RD), U30.15 (IO15)
/~CLKW: U27.10 (~WR), U30.22 (IO22)
/~CNT: U2.1 (1A), U30.19 (IO19)
/~CSYNC: R9.1, U19.80 (~CSYNC), U19B1.39 (~CSYNC)
/~DAE: U1.19 (CE), U30.4 (I4), U31.20 (I020)
/~DKRD: U20.37 (~DKRD), U20B1.37 (~DKRD)
/~DKWD: U20.38 (~DKWD), U20B1.38 (~DKWD)
/~DKWE: U20.39 (DKWE), U20B1.39 (DKWE)
/~DTACK: U28.17 (I03), U30.1 (I1), U31.18 (IO18), U37.17
/~HSYNC: U19.81 (~HSYNC), U19B1.40 (~HSYNC), X16.22
/~INT2: U20.16 (~INT2), U20B1.16 (~INT2)
/~INT3: U19.17 (~INTR), U20.17 (~INT3), U20B1.17 (~INT3)
/~INT6: U20.18 (~INT6), U20B1.18 (~INT6)
/~IPL0: U20.13 (~IPL0), U20B1.13 (~IPL0)
/~IPL1: U20.14 (~IPL1), U20B1.14 (~IPL1)
/~IPL2: U20.15 (~IPL2), U20B1.15 (~IPL2)
/~LDS: U19.52 (~LDS), U29.6 (I6), U30.9 (I9), U36.6
/~LPEN: U19.78 (~LPEN), U19B1.37 (~LPEN), X17.19
/~OVR: U28.7 (I7), U30.8 (I8), U31.8 (I8), U37.7
/~PRW: U19.22 (PRW), U29.4 (I4), U30.14 (I14), U36.4
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

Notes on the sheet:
Mainboard Interface
PLD
Memory Expansion
Custom Chipset
Video Slot
DECOUPLING
REALTIME CLOCK
REJ 74LS244
REJ 74LS373
MB 74LS244
~ROME
~RGAE
~DAE
~PALOPE
~RE
~DBR
257 HEADER
244 HEADER
HEADER
_CLKE

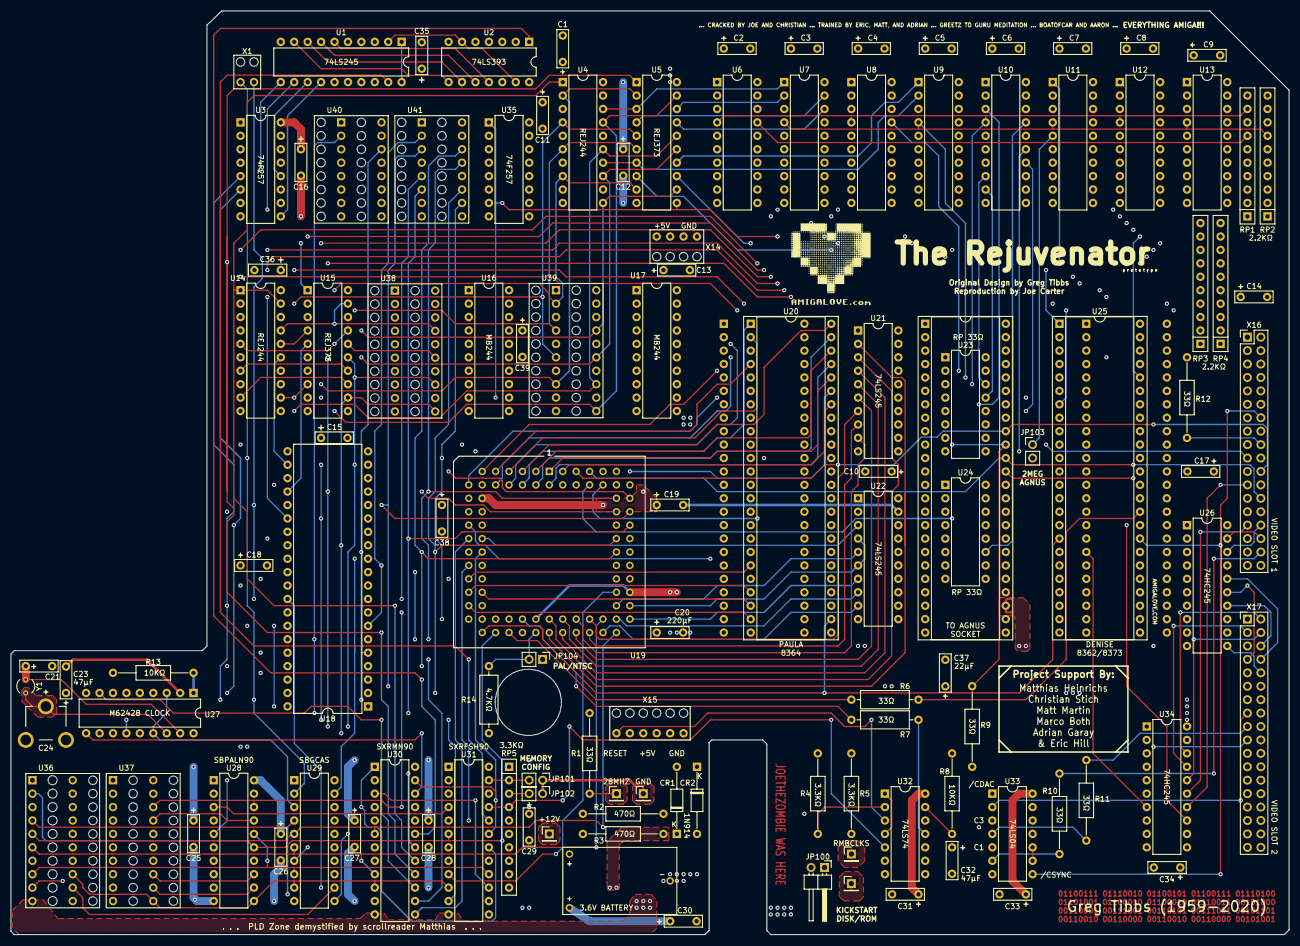
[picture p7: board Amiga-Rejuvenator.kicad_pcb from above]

Board: 4 copper layers, 241.8 x 174.8 mm, 120 parts (0 on the bottom side), 278 nets.

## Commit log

2021-05-06 update board silkscreen
2021-05-15 Signal name updates
    Signal name updates on KiCAD schematics and board artwork.
    [Amiga-Rejuvenator.kicad_pcb, Amiga-Rejuvenator.sch]
2021-05-15 Update board artwork
    Rejuvenator board artwork (KiCAD) updated with proper resistor and capacitor values.
    [Amiga-Rejuvenator.kicad_pcb]
2021-05-15 Fix track to close to via
    A7 track was run too close to via (_CDRREG). Increased spacing.
    [Amiga-Rejuvenator.kicad_pcb]
2021-05-16 Fix A7 track proximity
    A7 track was too close to via _CDRREJ
    [Amiga-Rejuvenator.kicad_pcb]
2021-05-22 Signal names and active low status updated
    [Amiga-Rejuvenator.kicad_pcb, Amiga-Rejuvenator.sch]
2021-05-24 GND trace cleanup
    [Amiga-Rejuvenator.kicad_pcb]
2021-05-24 Power plane update
    Eliminated redundant tracks placed inside fill zones.
    [Amiga-Rejuvenator.kicad_pcb]
2021-05-27 Add directional signals for Agnus. Add PWR_FLAG for power inputs.
    [Amiga-Rejuvenator.kicad_pcb, Amiga-Rejuvenator.sch]
2021-05-30 Signaling Update
    Updated signal direction for RAM, custom chips, and motherboard headers. Rejuvenator now completes the ERC check error free! (It previously had errors due to missing signal directions on the symbol entries.)
    Renamed nets that are connected by way of the mainboard. Previously, these nets were named (for example) X2.~CDW, X9.~CDW, X15.~CDW. Now these same signals would be named ~CDWa, ~CDWb, ~CDWc. Keep in mind, these are all the same signal. They are not connected on the rejuvenator itself, but they become interconnected once plugged to the mainboard. For example, all the CDWa,b,c signals are the same CDW signal, just fed up to Rejuvenator from different points on th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
    [Amiga-Rejuvenator.kicad_pcb, Amiga-Rejuvenator.sch]
2021-05-30 Create Rejuvenator Signal Flow.pdf
    Rejuvenator Signal Flow to help visualize how the board works. Details the busses and chip enable / output enable signals for each logic chip.
2021-06-06 Remove redundant traces
    Remove redundant power traces which were embedded in a fill zone.
    [Amiga-Rejuvenator.kicad_pcb]
2021-08-28 Restore Logo to PCB Artwork
    The logo was inadvertently missing from the board artwork.
    [Amiga-Rejuvenator.kicad_pcb]
2021-09-02 Copper pour cleanup
    [Amiga-Rejuvenator.kicad_pcb]
2021-10-17 Update board dimensions
    Relocate post hole position slightly down and to the left. Decrease width of upper right corner. Increase width of bottom notch.
    These locations had slight interference with the A1000 capacitors and posts, increasing the difficulty when installing Rejuvenator. These dimensions have now been fine-tuned for better clearance.
    [Amiga-Rejuvenator.kicad_pcb]
2021-10-26 Update board artwork
    [Amiga-Rejuvenator.kicad_pcb]
2021-10-26 Update board artwork
    Add support contributors
    [Amiga-Rejuvenator.kicad_pcb]
2021-11-21 Update BOM.txt
    Add warning concerning the use of shorter pin headers.
2022-03-10 Update BOM.txt
    Add missing RTC circuit capacitor values
2024-03-10 Add files via upload
    PDF version of the schematic, for those not wanting to install KiCAD to view.
2026-02-12 KiCad Render of the Rejuvenator
    KiCad Render of the Rejuvenator, for those not wanting to install KiCad.
